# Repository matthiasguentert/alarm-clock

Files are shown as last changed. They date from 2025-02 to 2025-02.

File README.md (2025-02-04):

# Arduino based Alarm Clock

This is a fun project I built for my daugther, where she led the design. The alarm clock features snooze functionality and - most importantely - a couple of selectable alarm sound tracks like a rooster, barking dog, etc. 😊

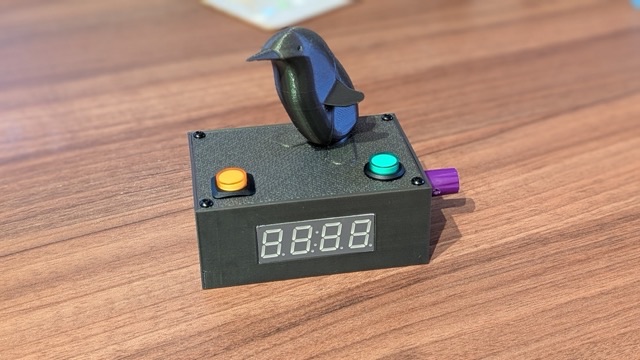
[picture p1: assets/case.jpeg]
Alarm Clock


For the logic I've used a finite state machine to control the events. The design uses entirely static methods and variables to reduce RAM usage. The snooze button got debounced with the famouse Bounce2 library.

FSM

A long press on the snooze button allows adjusting the time. To green latching button enables and disables the alaram. A press on the rotary button enters alarm setup mode, where the alarm time and alarm track can be selected.

## Hardware

### Electrical components

* Adafruit Feather 328p (https://www.adafruit.com/product/3458)
* DFPlayer Mini (DFR0299)
* Adafruit DS3231 RTC (https://www.adafruit.com/product/5188)
* Speaker 8 Ohm 2W
* Capacitor 470uF (for noise filtering)
* 7 Segment display HT16K33 bagback (https://www.adafruit.com/product/813)
* Adafruit Rotary Encoder (https://www.adafruit.com/product/4991) as a multiselect controller for setup
* Latching button with LED to enable/disable alaram (green)
* Momentary push button with LED for snooze (yellow)

### Case

The model was designed with FreeCAD and printed with a Prusa Mini+ using PLA. The source file can be found in the `model` folder.

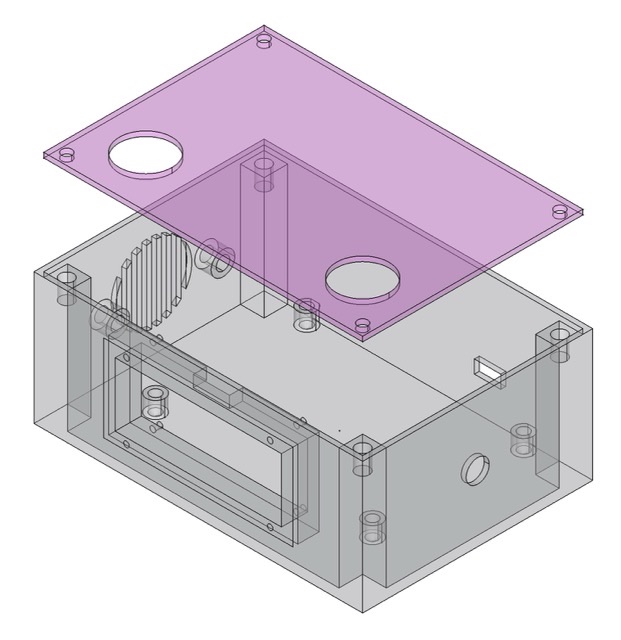
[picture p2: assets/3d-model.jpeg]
3D case


### Screwed connection

#### Printed threads

I had to carry out a couple of experiments to find a proper way for the threaded connections. First I started out with printed threads.

This serves well as a quick solution when 3d-printed with a higher resolution (smaller layer height) and used with the following parameters in FreeCAD.

- Select thread class `6H` (internal thread) or `6G` (external thread) when printing.
- When `Counterbore` then, use `Depth` of `2mm` for `M3` screws
- Add `0.10mm` to the depth to accommodate for build tolerances of the screw in its length
- Leave at least `2 mm`

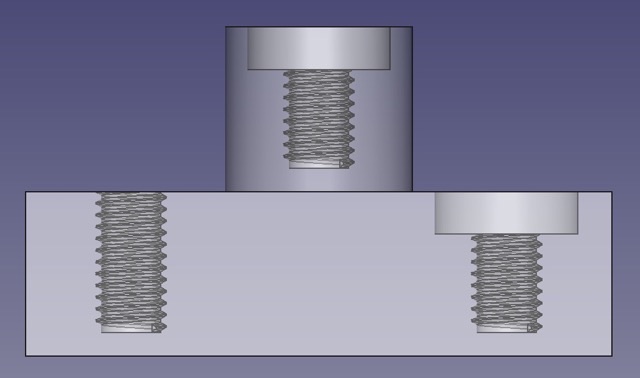
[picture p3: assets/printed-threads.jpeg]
printed threads 1

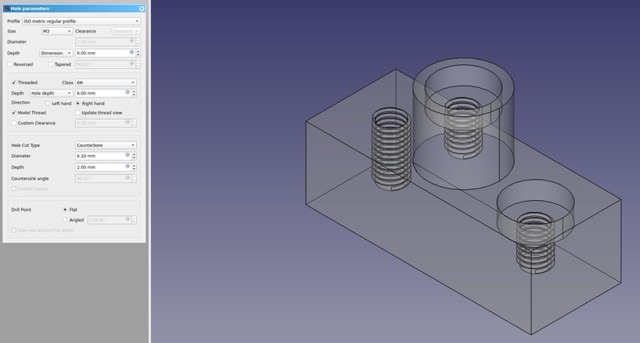
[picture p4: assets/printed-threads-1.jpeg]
printed threads 2


#### Melt-in thread inserts

Printed threads would have been sufficient for this type of project since there isn't much pulling force to be expected on the screws.

Still I decided against it in favour of melt-in thread inserts which simplify the 3D modelling process and assembling. Also it gives the case a more professional look!

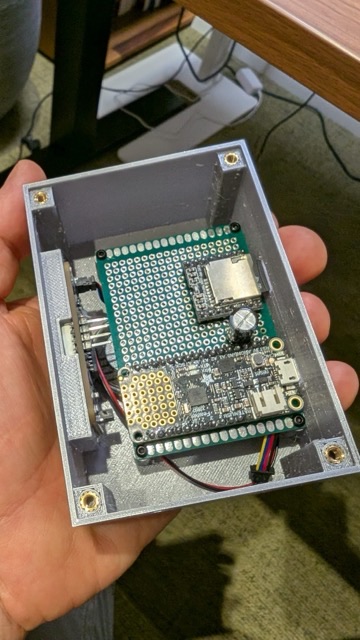
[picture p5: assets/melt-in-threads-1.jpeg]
melt-in threads 1

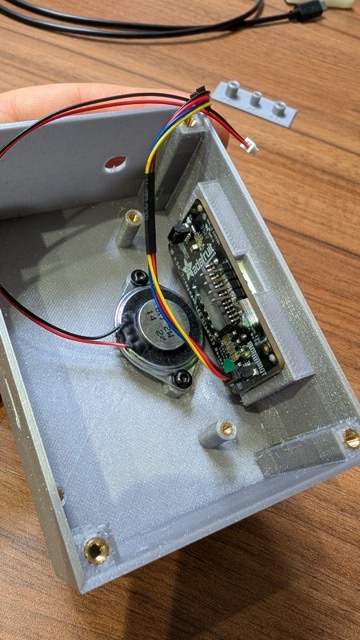
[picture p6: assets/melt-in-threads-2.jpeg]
melt-in threads 2

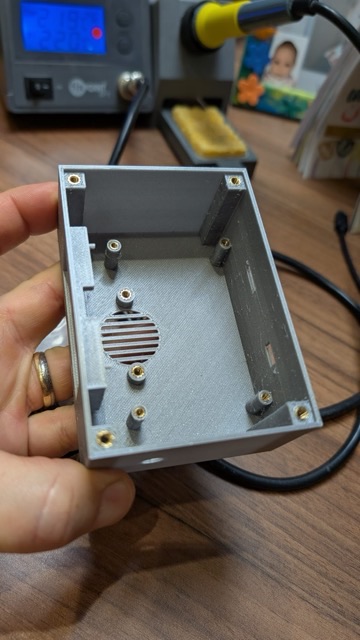
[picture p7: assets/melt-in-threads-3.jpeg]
melt-in threads 3


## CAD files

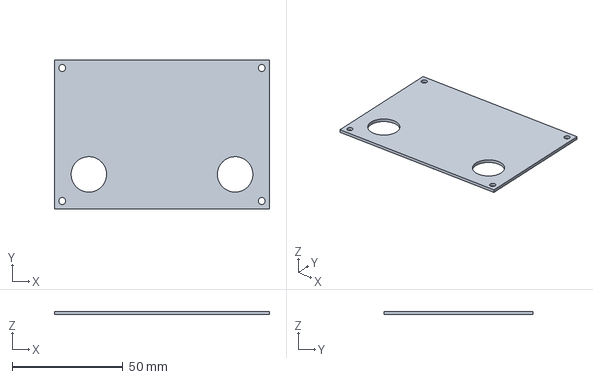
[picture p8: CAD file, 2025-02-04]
model/alarm-clock-housing-v5.FCStd
97.0 x 67.0 x 1.50 mm

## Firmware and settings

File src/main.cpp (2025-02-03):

#include <Arduino.h>
#include <Fsm.h>

#define A_SECOND 1000
#define A_MINUTE 60000

#include "Debug.hpp"
#include "Display.hpp"
#include "Clock.hpp"
#include "Player.hpp"
#include "StateManager.hpp"
#include "Encoder.hpp"
#include "EventHandler.hpp"

const PlayerConfig playerConfig = {
    .volumeLevel = 14, // 0 (min) - 30 (max)
    .softwareSerialRxPin = 5,
    .softwareSerialTxPin = 6};

const DisplayConfig displayConfig = {
    .brighthness = 5}; // 0 (min) - 15 (max)

const ClockConfig clockConfig = {
    .interruptPin = 2, // INT0
    .snoozeButtonPin = 14,
    .snoozeButtonLedPin = 15,
    .alarmSwitchPin = 16,
    .alarmSwitchLedPin = 17};

const AlarmConfig alarmConfig = {
#ifdef DEBUG
    .snoozeDurationMs = 10 * A_SECOND
#else
    .snoozeDurationMs = 5 * A_MINUTE
#endif
};

const EncoderConfig encoderConfig = {
    .addr = 0x36,
    .pin = 24,
    .debounceIntervalMs = 5};

void setup()
{
    D_SerialBeginAndWait(9600);

    StateManager::setup(alarmConfig);
    Player::setup(playerConfig);
    Display::setup(displayConfig);
    Clock::setup(clockConfig);
    Encoder::setup(encoderConfig);

    D_println(">> Startup complete");
}

void loop()
{
    StateManager::fsm.run_machine();

    static unsigned long pressStartTime = 0;
    static bool isLongPress = false;

    Clock::snoozeButton.update();

    if (Clock::snoozeButton.fell())
    {
        pressStartTime = millis();
        isLongPress = false;
    }

    if (Clock::snoozeButton.read() == LOW && !isLongPress)
    {
        if (millis() - pressStartTime > 5 * A_SECOND)
        {
            isLongPress = true;
            D_println(">> long press");
            StateManager::fsm.trigger(TIME_SETUP_EVENT);
        }
    }

    if (Clock::isAlarmEnabled() && Clock::alarmFired())
    {
        StateManager::fsm.trigger(ALARM_EVENT);
    }

    if (Encoder::pressed())
    {
        StateManager::fsm.trigger(ALARM_TIME_SETUP_EVENT);
    }
}

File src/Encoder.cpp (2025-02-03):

#include "Encoder.hpp"

int32_t Encoder::encoderValue;
EncoderConfig Encoder::config;
Adafruit_seesaw Encoder::ss;
bool Encoder::lastButtonState;
uint64_t Encoder::lastDebounceTime;
bool Encoder::buttonState;
bool Encoder::buttonPressed;

void Encoder::setup(const EncoderConfig &config)
{
    D_println(">> Encoder setup");

    Encoder::config = config;
    Encoder::encoderValue = 0;

    while (!ss.begin(config.addr))
    {
        D_println(">> Encoder initializing...");
        delay(10);
    };

    ss.pinMode(config.pin, INPUT_PULLUP);
}

// returns the encoder value in a cyclic fashion
int32_t Encoder::getPosition(int32_t maxValue)
{
    uint32_t delta = ss.getEncoderDelta();
    encoderValue += delta;

    if (encoderValue < 0)
    {
        encoderValue = (encoderValue + maxValue) % (maxValue);
    }
    else if (encoderValue > maxValue - 1)
    {
        encoderValue = encoderValue % (maxValue);
    }

    return encoderValue;
}

void Encoder::setPosition(int32_t position)
{
    encoderValue = position;
    ss.setEncoderPosition(position);
}

bool Encoder::pressed()
{
    // Read the state of the push button
    bool reading = ss.digitalRead(config.pin);

    if (reading != lastButtonState)
    {
        lastDebounceTime = millis(); // Reset the debounce timer
    }

    // If the button state has remained stable for longer than the debounce delay
    if ((millis() - lastDebounceTime) > config.debounceIntervalMs)
    {
        // If the button state has changed, update the buttonState
        if (reading != buttonState)
        {
            buttonState = reading;

            // Check if the new button state is LOW (button pressed)
            if (buttonState == LOW)
            {
                buttonPressed = true;
                return true;
            }
        }
    }

    lastButtonState = reading;

    return false;
}

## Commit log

2025-01-20 🏓 initial commit
2025-02-04 additional files (#1)
    * adds project description
    * adds fsm diagram
    * adds details
    * updates images
    [alarm-clock-housing-v5.FCStd]
2025-02-07 ♻️ refactor: move source files from 'lib' directory to 'src' directory (#2)
